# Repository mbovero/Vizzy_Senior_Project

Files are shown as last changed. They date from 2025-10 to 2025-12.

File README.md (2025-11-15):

<div align="center" style="margin-top:16px;margin-bottom:12px;">
  <h1 style="margin:0 0 6px 0;font-size:38px;line-height:1.15;letter-spacing:.3px;">
    Vizzy: Enhancing Robotic Manipulation with Vision-Enabled Large Language Models
  </h1>

  <div style="font-size:14px;color:#6a737d;margin-bottom:10px;">
    University of Utah — Electrical & Computer Engineering Capstone
  </div>

  <div style="font-size:15px;margin-bottom:14px;">
    Authors: Burke Dambly · Miles Bovero · Lawrence Ponce · Brian Stites · Jesse Jenkins
  </div>
  <br>
  <!-- tech badges -->
  <div style="margin-bottom:14px;">
    
    
    
    
    
  </div>

  <hr style="margin:0 auto;border:0;height:1px;width:90%;background:linear-gradient(90deg,rgba(0,0,0,0),rgba(140,140,140,.35),rgba(0,0,0,0));" />
</div>

## System Showcase
<!-- Two side-by-side GIFs -->
<div align="center" style="display:flex; justify-content:center; gap:20px; margin-top:20px; margin-bottom:16px;">
  Vizzy motion demo
  Vizzy vision detection demo
</div>

<p align="center" style="font-size:14px; color:#666;">
  <em>Figure 1 — Left: Arm motion demonstration · Right: Vision-based object detection in action.</em>
</p>

## Overview

<!-- Overview Section -->
<div style="margin-top:24px; margin-bottom:24px; padding:18px 22px; border-left:4px solid #2563eb; background:rgba(37,99,235,0.05); border-radius:8px;">
  <p style="margin:0 0 12px 0;">
    <strong>Vizzy</strong> is a modular 5-axis robotic arm designed to demonstrate the integration of 
    <strong>computer vision</strong>, <strong>inverse kinematics</strong>, and 
    <strong>large language model (LLM)</strong> reasoning for adaptive robotic control.  
    The project explores how artificial intelligence can make robotic systems more flexible and user-friendly 
    by combining visual perception and semantic reasoning into a single integrated robotic platform.
  </p>

  <p style="margin:0;">
    Unlike traditional robotic systems that require explicit programming and rigid motion paths, Vizzy enables 
    high-level natural language interaction. Through vision-based object detection and LLM-driven task scheduling, 
    the system can autonomously interpret and execute user requests.
  </p>
</div>

<p align="center">
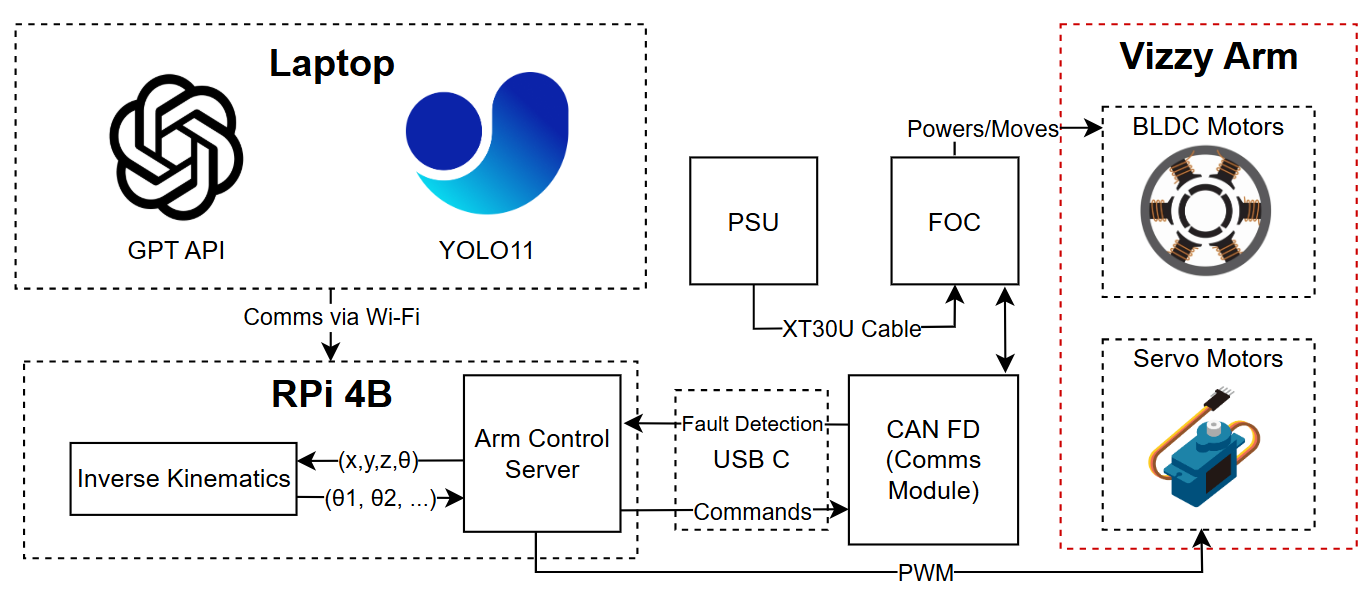
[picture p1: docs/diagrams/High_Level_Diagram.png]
Vizzy System Diagram
  
</p>

<p align="center"><em>Figure 2 — Conceptual overview of Vizzy’s modular arm system.</em></p>

<hr style="margin-top:28px; margin-bottom:0; border:0; height:1px; background:linear-gradient(90deg,rgba(0,0,0,0),rgba(140,140,140,.35),rgba(0,0,0,0));" />

## System Architecture

### Hardware

- **Motors:** MJBOTS mj5208 BLDC outrunner motors  
- **Motor Controllers:** Moteus r.11 (Field-Oriented Control)  
- **Microcontrollers:** Raspberry Pi 4B
- **Sensors:** 16MP USB camera and VL53L1X time-of-flight sensor  
- **Communication:** CAN-FD network using the Moteus protocol  
- **Structure:** CNC-milled T2-grade aluminum and PETG-CF 3D-printed components   
- **Power Supply:** Mean Well 24V .625A DC Power Supply 

<!-- 3x2 image grid for README -->
<table align="center">
  <tr>
    <td align="center">
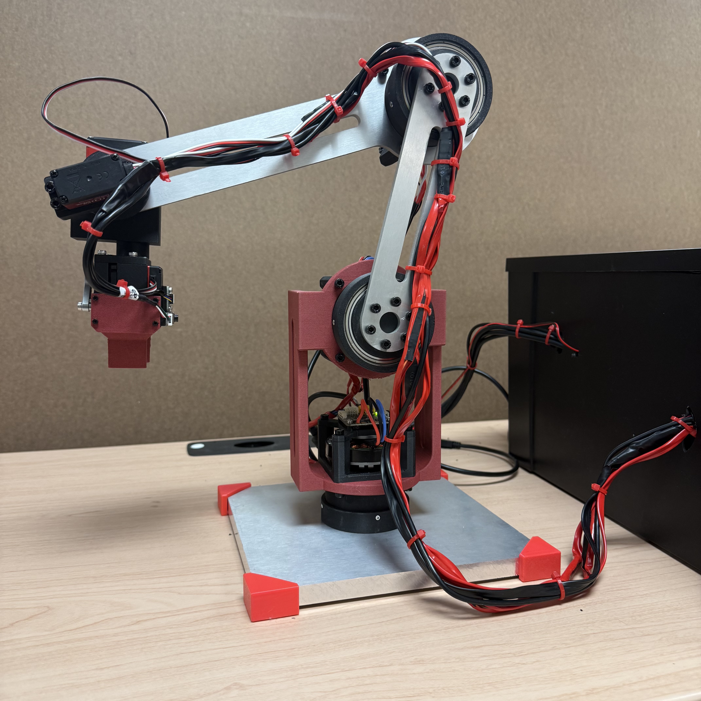
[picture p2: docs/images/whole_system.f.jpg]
Arm Assembly
      
      <div style="font-size:12px;color:#999;margin-top:6px;">Vizzy System</div>
    </td>
    <td align="center">
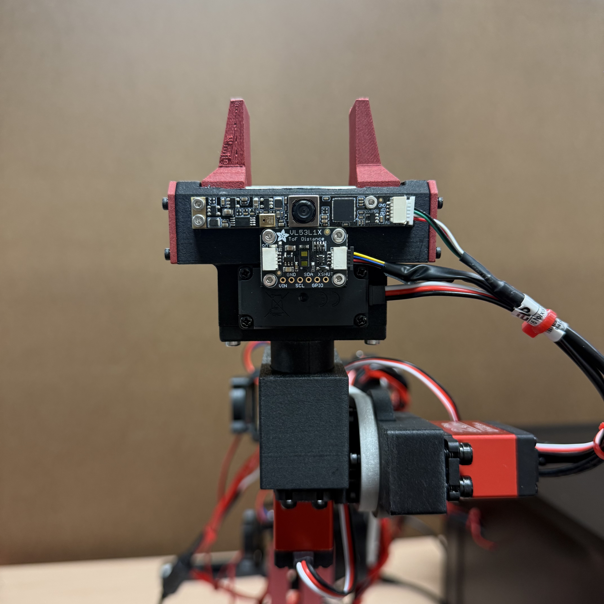
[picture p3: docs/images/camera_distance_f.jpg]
Joint Close-Up
      
      <div style="font-size:12px;color:#999;margin-top:6px;">Camera and ToF Sensor</div>
    </td>
    <td align="center">
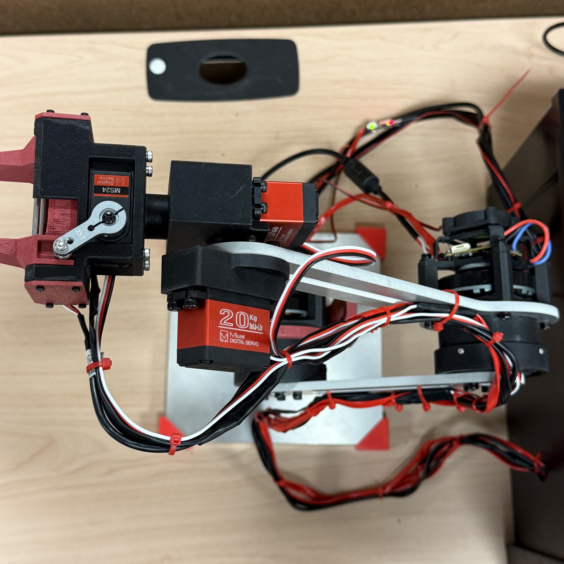
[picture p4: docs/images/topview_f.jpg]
Moteus Controllers
      
      <div style="font-size:12px;color:#999;margin-top:6px;">Upper Assembly</div>
    </td>
  </tr>
  <tr>
    <td align="center">
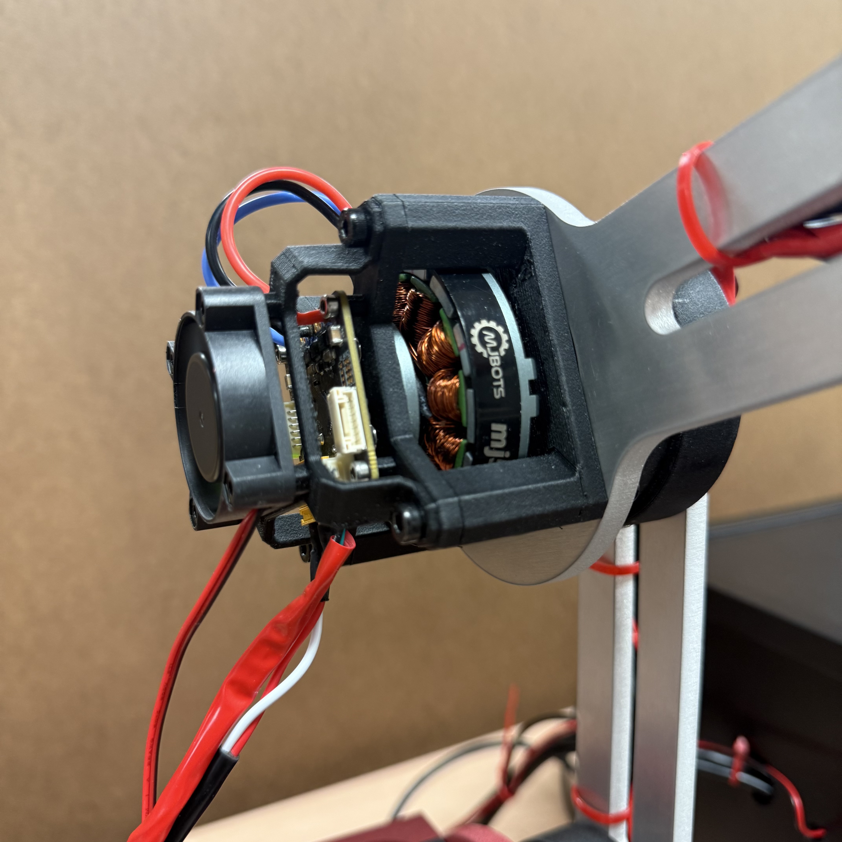
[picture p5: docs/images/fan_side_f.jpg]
Electronics Hub
      
      <div style="font-size:12px;color:#999;margin-top:6px;">Cooling System</div>
    </td>
    <td align="center">
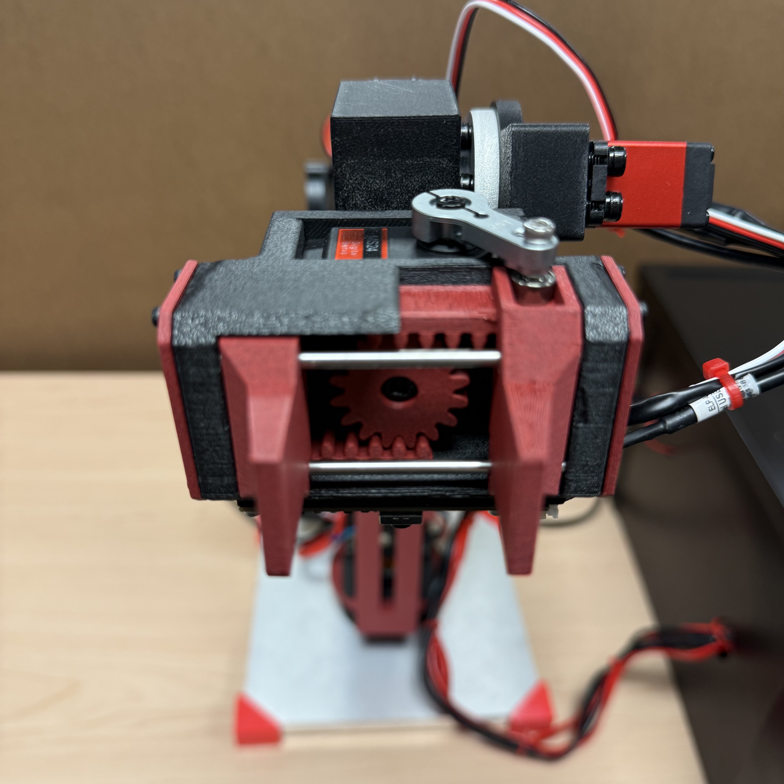
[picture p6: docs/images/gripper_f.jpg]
Camera Mount
      
      <div style="font-size:12px;color:#999;margin-top:6px;">End Effector</div>
    </td>
    <td align="center">
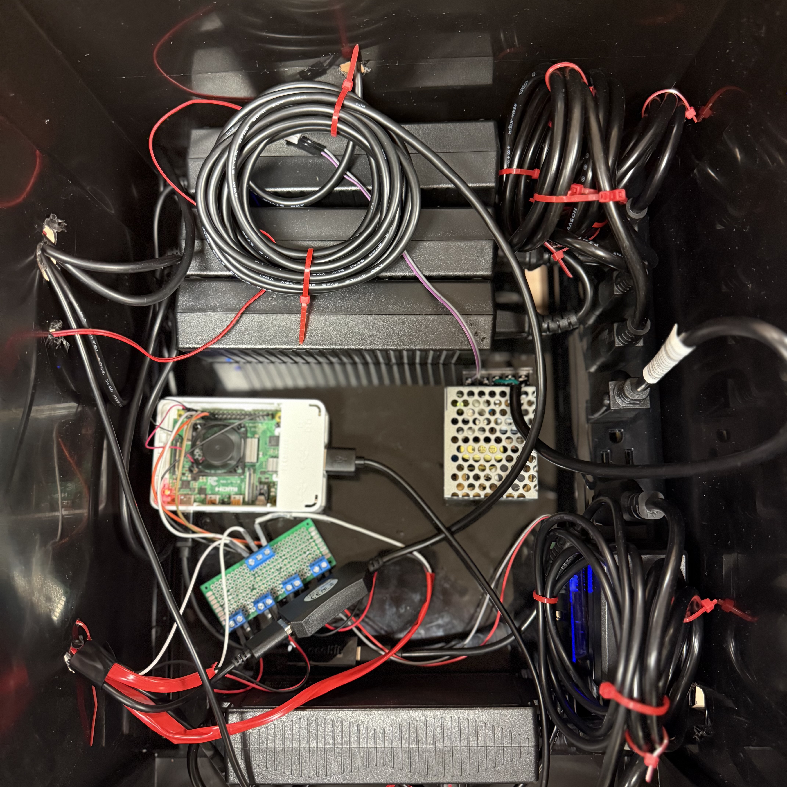
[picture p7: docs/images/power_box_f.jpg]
Power System
      
      <div style="font-size:12px;color:#999;margin-top:6px;">"Black Box" Power</div>
    </td>
  </tr>
</table>

<p align="center"><em>Figure 3 — Hardware overview showing mechanical components.</em></p>

<h3 id="software">Software</h3>

<ul style="margin-top:6px;margin-bottom:12px;">
  <li><strong>Vision Stack:</strong> YOLO11 model for object classification and mask segmentation</li>
  <li><strong>Semantic Layer:</strong> LLM-based contextual enrichment of detected objects</li>
  <li><strong>Task Scheduler:</strong> LLM-based task composition based on user request</li>
  <li><strong>Control Framework:</strong> Python API for inverse kinematics and task execution</li>
</ul>

<p align="center" style="margin-top:10px;">
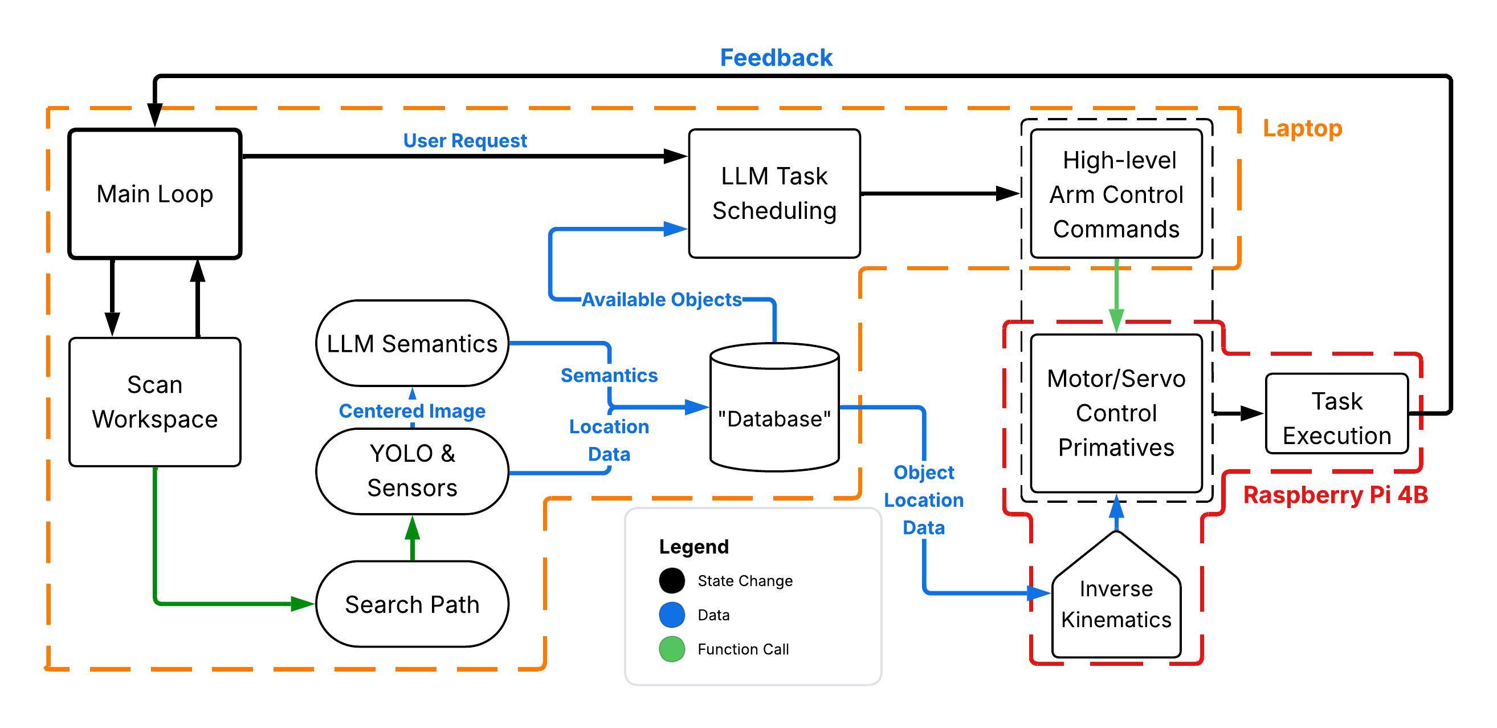
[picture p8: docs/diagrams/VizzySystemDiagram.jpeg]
Software Architecture Diagram
  
</p>
<p align="center" style="margin-top:4px;">
  <em>Figure 4 — Software architecture illustrating perception, reasoning, and control flow.</em>
</p>

---
<h2 id="about-the-authors" align="center">About the Authors</h2>

<table style="width:100%;border-collapse:separate;border-spacing:18px 14px;">
  <tr align="center" valign="top">
    <td style="width:33%;border:1px solid #d0d7de;border-radius:10px;padding:16px;background:#fafbfc;">
      <strong>Burke Dambly</strong><br>
      <em style="color:#57606a;">Computer Engineering</em><br>
      Focused on control systems, embedded firmware, and integration of Moteus-controlled BLDC actuators with high-level Python logic.
    </td>
    <td style="width:33%;border:1px solid #d0d7de;border-radius:10px;padding:16px;background:#fafbfc;">
      <strong>Miles Bovero</strong><br>
      <em style="color:#57606a;">Computer Engineering</em><br>
      Designed subsystem interfaces, YOLO-based vision pipeline, object centering / location / orientation estimation algorithms.
    </td>
    <td style="width:33%;border:1px solid #d0d7de;border-radius:10px;padding:16px;background:#fafbfc;">
      <strong>Lawrence Ponce</strong><br>
      <em style="color:#57606a;">Computer Engineering</em><br>
      Developed semantic enrichment and LLM-based task scheduling, enabling natural language driven task execution.
    </td>
    
  </tr>

  <tr align="center" valign="top">
    <td style="width:33%;border:1px solid #d0d7de;border-radius:10px;padding:16px;background:#fafbfc;">
      <strong>Brian Stites</strong><br>
      <em style="color:#57606a;">Computer Engineering</em><br>
      Designed and assembled the power distribution and safety systems for the robotic arm.
    </td>
    <td style="width:33%;border:1px solid #d0d7de;border-radius:10px;padding:16px;background:#fafbfc;">
      <strong>Jesse Jenkins</strong><br>
      <em style="color:#57606a;">Computer Science</em><br>
      Contributed to the inverse kinematics (IK) framework for precise arm positioning and control.
    </td>
    <td style="width:33%;border:1px dashed #d0d7de;border-radius:10px;padding:16px;background:#fafbfc;">
      <strong>Neal Patwari</strong><br>
      <em style="color:#57606a;">Faculty Advisor</em><br>
      Provided guidance on system integration and research methodology throughout the Vizzy capstone project.
    </td>
  </tr>
</table>

## Acknowledgements

This project was developed as part of the University of Utah Electrical and Computer Engineering Capstone Program.  
Special thanks to the faculty mentors and the Utah Machine Shop for technical support and machining resources.

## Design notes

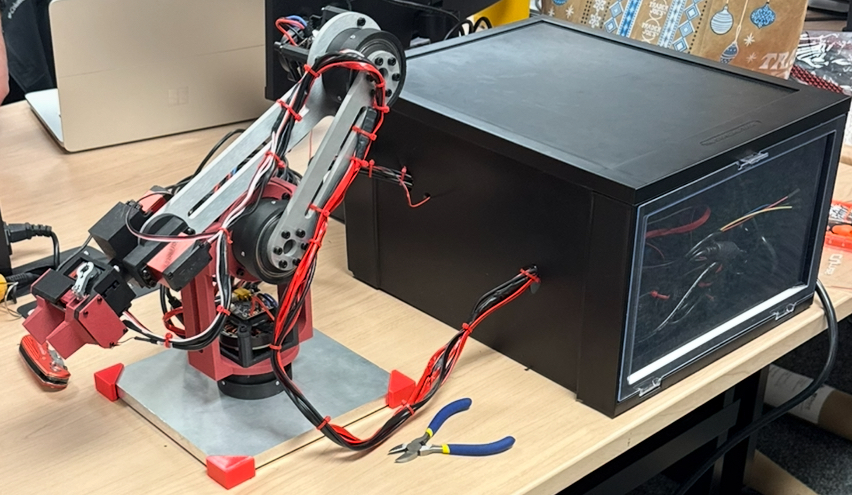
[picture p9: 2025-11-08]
docs/images/ArmOnDesk.jpg

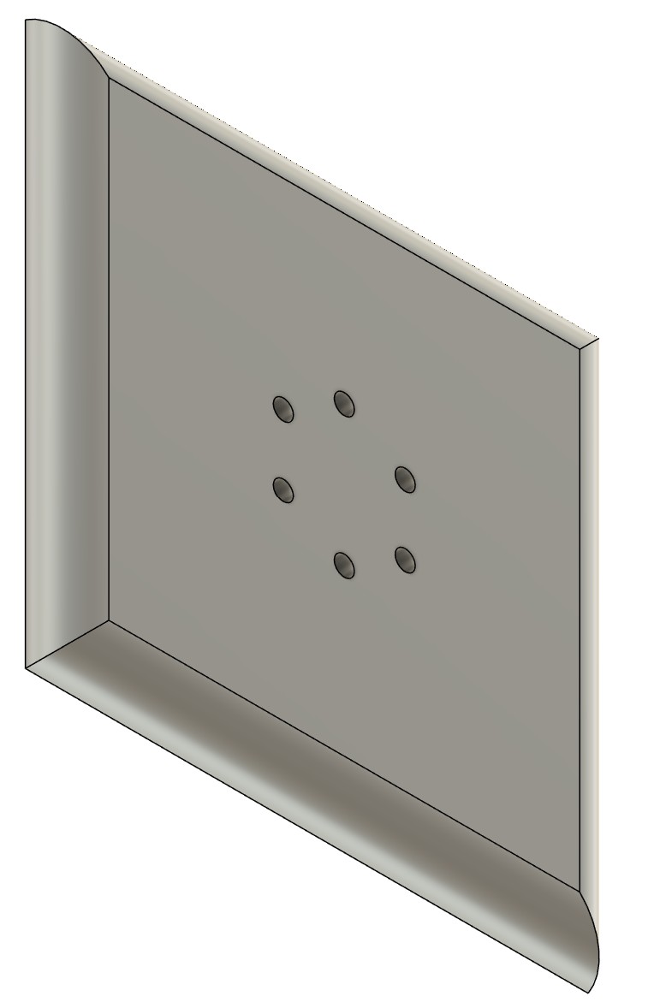
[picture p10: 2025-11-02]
docs/CAD/screenshots/Base v1.jpg

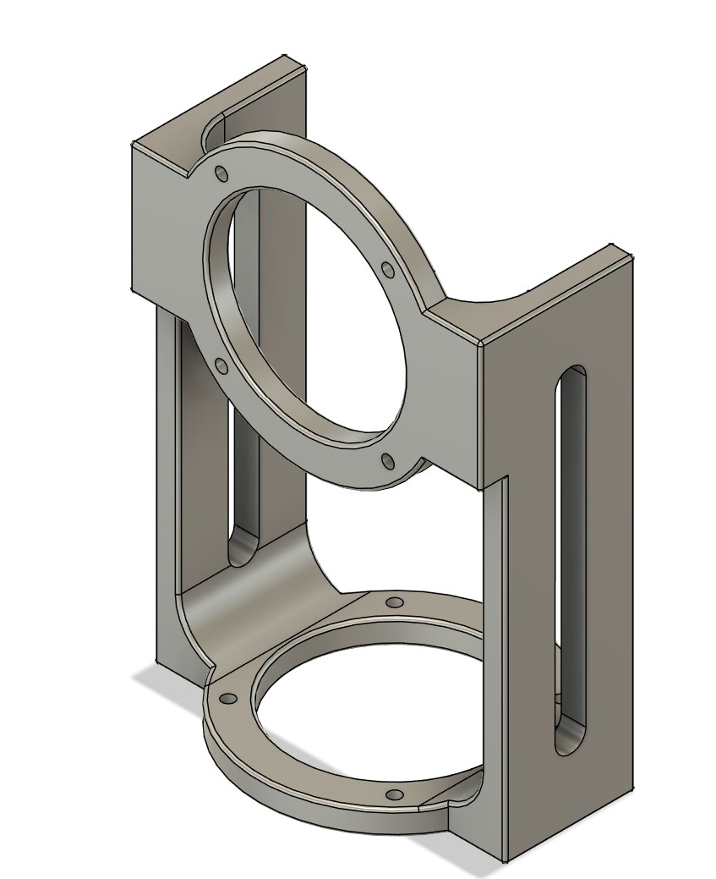
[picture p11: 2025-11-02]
docs/CAD/screenshots/Bottom Linkage v9.jpg

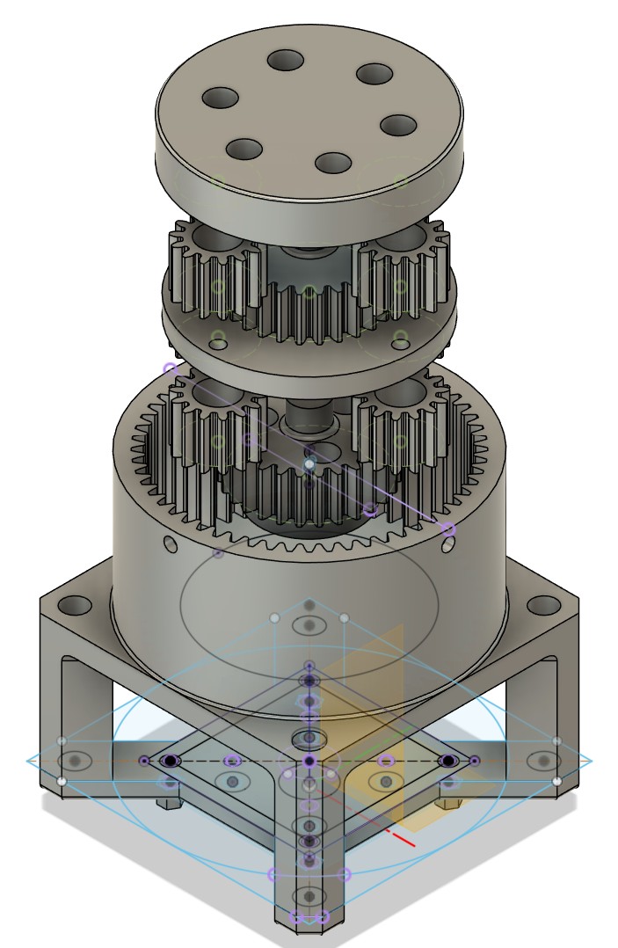
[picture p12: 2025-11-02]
docs/images/C1Gearbox.jpg

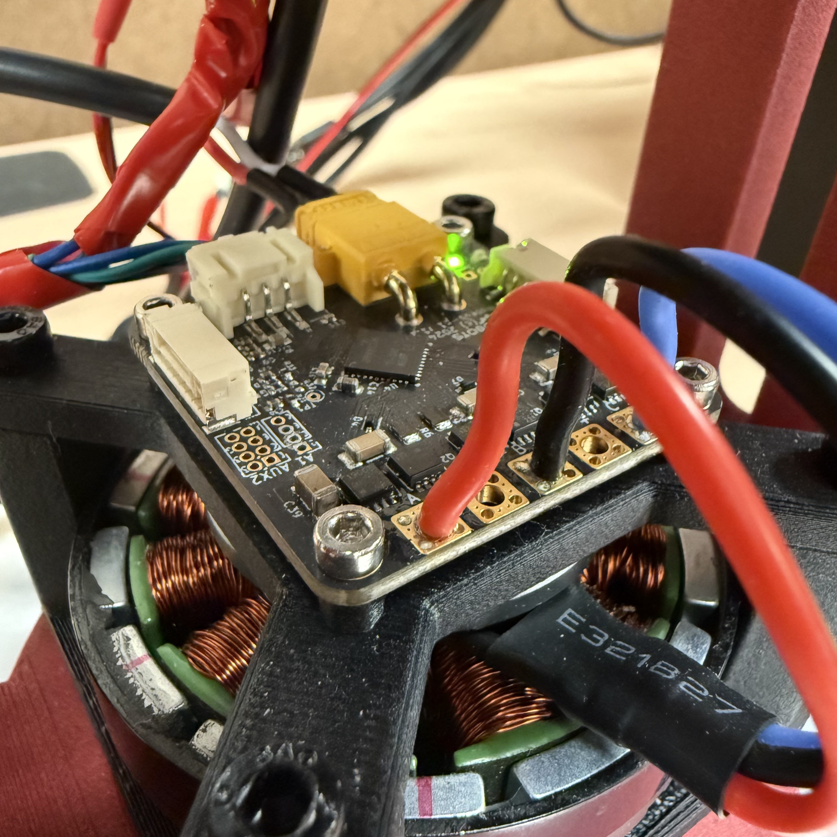
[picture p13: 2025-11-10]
docs/images/moteus_c_f.jpg

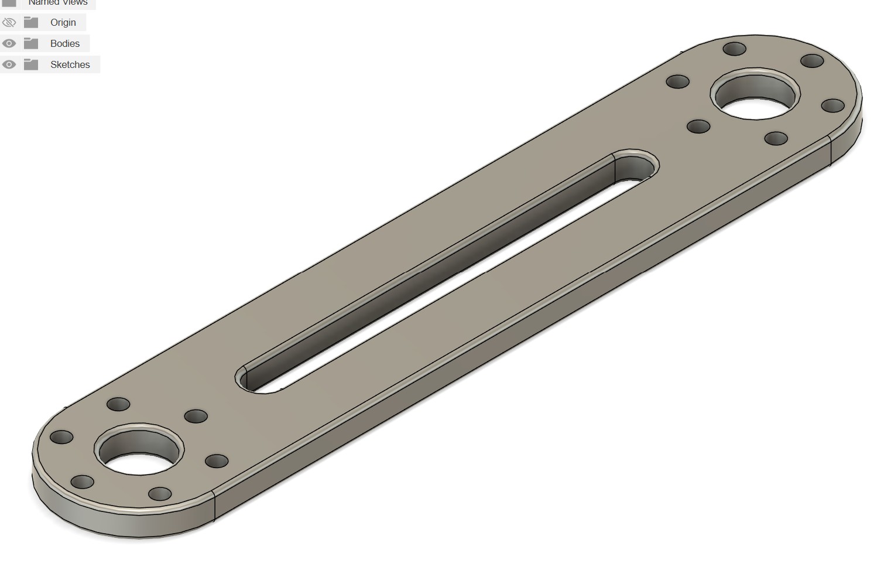
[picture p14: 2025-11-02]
docs/CAD/screenshots/Arm Link v5.jpg

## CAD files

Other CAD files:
docs/CAD/raw/20Kg Servo Bracket v6.f3d
docs/CAD/raw/Arm Link v5.f3d
docs/CAD/raw/Base Bracket v7.f3d
docs/CAD/raw/Base v1.f3d
docs/CAD/raw/Bottom Linkage v9.f3d
docs/CAD/raw/Custom C1 Bracket v3.f3d
docs/CAD/raw/Down Bracket v2.f3d
docs/CAD/raw/End Effector v16.f3d
docs/CAD/raw/Experimental Hold v13.f3d
docs/CAD/raw/Fan Bracket v2.f3d
docs/CAD/raw/Gripper v30.f3d
docs/CAD/raw/Upper Arm v4.f3d

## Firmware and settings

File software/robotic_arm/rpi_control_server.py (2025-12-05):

#!/usr/bin/env python3
# rpi_arm_server.py — Pi-side control of 3 moteus motors + 3 GPIO hobby servos (pitch, yaw, claw)
# Protocol (from client):  ik x y z pitch_rad yaw_rad O|C
#   - Pitch: radians go into IK; we use IK's q4 (PWM) directly (preserves original behavior)
#   - Yaw:   radians mapped to your specified PWM endpoints
#   - Claw:  O=1700 (open), C=1200 (closed) - snaps immediately (no interpolation)
# Pitch and yaw servos tween in sync with the motor group move duration. Claw snaps immediately.

from __future__ import annotations
import argparse, asyncio, math, time, sys, contextlib, pprint, re

# ---------- Servo Pins (BCM) ----------
SERVO_YAW   = 4
SERVO_CLAW  = 17
SERVO_PITCH = 27

# ---------- Global PWM bounds ----------
SERVO_MIN    = 500
SERVO_MAX    = 2500

# Pitch center (original server behavior: pitch straight up)
SERVO_PITCH_CENTER = 1770

# Yaw PWM mapping (your exact endpoints)
YAW_PWM_CENTER = 1700
YAW_PWM_MIN    = 1025   # clockwise (negative)
YAW_PWM_MAX    = 2375   # counter-clockwise (positive)
YAW_RAD_MIN    = -math.pi/2   # -90°
YAW_RAD_MAX    =  math.pi/2   # +90°

# Claw PWM mapping (your exact endpoints)
CLAW_PWM_OPEN   = 1650
CLAW_PWM_CLOSED = 1300

# Tween timing for servos
SERVO_TWEEN_MIN_DT = 0.01   # s
SERVO_TWEEN_MAX_DT = 0.025  # s
IDLE_SLEEP          = 0.02   # s
DURATION_FLOOR_S    = 0.1    # s (if motors barely move)

# ---------- Moteus / IK ----------
import moteus
from ik_callable import make_default_arm, ik_cmds_bounded

# ---- IK Tunables ----
IK_RADIUS_M = 0.15
IK_Z_MIN    = 0.0
IK_Z_MAX    = 0.4

# ---- q2 linear scaling (map ±2.25 -> ±2.10, 0 -> 0) ----
Q2_MAX_IN   = 2.25
Q2_MAX_OUT  = 2.15
Q2_SCALE    = (Q2_MAX_OUT / Q2_MAX_IN)  # ~0.955...

# ---- Comm/Heartbeat ----
COMM_FAIL_THRESHOLD = 3
RECOVER_SLEEP_S     = 0.5
HEARTBEAT_S         = 2.0

# pigpio
try:
    import pigpio
except Exception as e:
    print("ERROR: pigpio not available. Install via: sudo apt-get install pigpio", file=sys.stderr)
    raise

# Optional transports
def build_transport(kind: str):
    kind = (kind or "pi3hat").lower()
    if kind == "pi3hat":
        try:
            import moteus_pi3hat
            return moteus_pi3hat.Pi3HatRouter()
        except Exception:
            print("WARN: pi3hat not available, falling back to default moteus transport.", file=sys.stderr)
            return None
    if kind.startswith("socketcan"):
        parts = kind.split(":", 1)
        iface = parts[1] if len(parts) > 1 else "can0"
        try:
            return moteus.SocketcanRouter(channel=iface)
        except Exception:
            print(f"WARN: socketcan {iface} not available, using default.", file=sys.stderr)
            return None
    return None

# ---- Tunables (motors) ----
ID1, ID2, ID3      = 1, 2, 3

REST1               = 0.0
REST2               = 1.0
REST3               = 3.25

STEP_SIZE_RAD       = 0.08
STEP_DELAY_S        = 0.01

ACCEL_LIMIT         = 4
VEL_LIMIT           = 8.0
HOLD_ACCEL_LIMIT    = 4.0
HOLD_VEL_LIMIT      = 4.0
WATCHDOG            = 15.0

GROUP_SPEED_RAD_S   = 1.6
ACCEL_MULT          = 2.4
MIN_SPEED           = 0.02
POS_TOL             = 0.01
SYNC_POLL_S         = 0.05
SYNC_TIMEOUT_EXTRA  = 0.1

TEMP_LIMIT          = 50.0
COOL_RESUME_TEMP    = 40.0

WIGGLE_AMPLITUDE    = 0.5
WIGGLE_REPS         = 2
WIGGLE_DWELL_S      = 0.15

# ---------- Helpers ----------
def ang_err(a: float, b: float) -> float:
    return math.remainder(a - b, 2.0 * math.pi)

def clamp(v, lo, hi):
    return lo if v < lo else hi if v > hi else v

def lerp(a, b, t):
    return a + (b - a) * t

def map_yaw_rad_to_pwm(rad: float) -> int:
    """Piecewise map radians to PWM using the exact center/min/max."""
    r = max(YAW_RAD_MIN, min(YAW_RAD_MAX, rad))
    if abs(r) < 1e-12:
        return YAW_PWM_CENTER
    if r < 0.0:
        # [YAW_RAD_MIN .. 0] -> [YAW_PWM_MIN .. YAW_PWM_CENTER]
        t = (r - YAW_RAD_MIN) / (0.0 - YAW_RAD_MIN)  # 0 at min, 1 at 0
        pwm = YAW_PWM_MIN + t * (YAW_PWM_CENTER - YAW_PWM_MIN)
    else:
        # [0 .. YAW_RAD_MAX] -> [YAW_PWM_CENTER .. YAW_PWM_MAX]
        t = r / YAW_RAD_MAX  # 0 at 0, 1 at max
        pwm = YAW_PWM_CENTER + t * (YAW_PWM_MAX - YAW_PWM_CENTER)
    return int(round(clamp(pwm, SERVO_MIN, SERVO_MAX)))

async def hold(ctrl: moteus.Controller, pos: float):
    await ctrl.set_position(
        position=float(pos),
        velocity=float('nan'),
        accel_limit=HOLD_ACCEL_LIMIT,
        velocity_limit=HOLD_VEL_LIMIT,
        watchdog_timeout=WATCHDOG,
        query=False,
    )

async def move_ramped(ctrl: moteus.Controller, current: float, target: float) -> float:
    delta = ang_err(target, current)
    steps = max(1, int(abs(delta) / STEP_SIZE_RAD))
    step  = delta / steps
    pos   = current
    for _ in range(steps):
        pos += step
        await hold(ctrl, pos)
        await asyncio.sleep(STEP_DELAY_S)
    await hold(ctrl, target)
    return target

# on_duration callback receives the chosen group move duration (seconds)
async def move_group_sync_time(items, on_duration=None):
    if not items:
        return []
    deltas = [ang_err(t, c) for (_, c, t) in items]
    max_delta = max(abs(d) for d in deltas) if deltas else 0.0

    if max_delta < 1e-9:
        duration = DURATION_FLOOR_S
        if on_duration is not None:
            asyncio.create_task(on_duration(duration))
        await asyncio.gather(*(hold(ctrl, tgt) for (ctrl, _, tgt) in items))
        return [t for (_, _, t) in items]

    group_speed = max(GROUP_SPEED_RAD_S, MIN_SPEED)
    duration = max(max_delta / group_speed, DURATION_FLOOR_S)

    if on_duration is not None:
        asyncio.create_task(on_duration(duration))

    cmds = []
    for (ctrl, cur, tgt), d in zip(items, deltas):
        vel_lim = max(abs(d) / duration, MIN_SPEED)
        acc_lim = max(vel_lim * ACCEL_MULT, ACCEL_LIMIT)
        cmds.append(ctrl.set_position(
            position=float(tgt),
            velocity=float('nan'),
            accel_limit=acc_lim,
            velocity_limit=vel_lim,
            watchdog_timeout=WATCHDOG,
            query=False,
        ))
    await asyncio.gather(*cmds)

    t_end = time.monotonic() + duration + SYNC_TIMEOUT_EXTRA
    ctrls   = [ctrl for (ctrl, _, _) in items]
    targets = [t for (_, _, t) in items]

    while True:
        if time.monotonic() >= t_end:
            break
        try:
            states = await asyncio.gather(*(ctrl.query() for ctrl in ctrls))
            pos = [float(st.values.get('position', 0.0)) for st in states]
        except Exception:
            pos = [None] * len(ctrls)

        if all(p is not None and abs(ang_err(t, p)) <= POS_TOL
               for p, t in zip(pos, targets)):
            break
        await asyncio.sleep(SYNC_POLL_S)

    await asyncio.gather(*(hold(ctrl, tgt) for ctrl, tgt in zip(ctrls, targets)))
    return targets

def extract_temperature(vals: dict):
    try:
        temp = vals.get(moteus.Register.TEMPERATURE)
        if isinstance(temp, (int, float)):
            return float(temp)
    except Exception:
        pass
    temp = vals.get(0x00e)
    if not isinstance(temp, (int, float)):
        temp = vals.get(14)
    return float(temp) if isinstance(temp, (int, float)) else None

def extract_voltage(vals: dict):
    for k in ("voltage", "motor_voltage", "bus_voltage",
              getattr(moteus, "Register", object()).__dict__.get("VOLTAGE") if hasattr(moteus, "Register") else None,
              0x010, 16):
        if k in vals and isinstance(vals[k], (int, float)):
            return float(vals[k])
    return None

def has_fault(vals: dict) -> bool:
    f = vals.get("fault", 0)
    if isinstance(f, (int, float)) and f != 0:
        return True
    for k, v in vals.items():
        kn = str(k).lower()
        if kn.startswith("fault") or kn.startswith("error"):
            if isinstance(v, (int, float)) and v != 0:
                return True
            if isinstance(v, str) and v.strip():
                return True
    return False

def collect_fault_fields(vals: dict) -> dict:
    out = {}
    for key in ("fault", "fault_state", "fault_code", "fault_information", "error", "last_error"):
        if key in vals:
            out[key] = vals[key]
    for k, v in vals.items():
        kn = str(k).lower()
        if (kn.startswith("fault") or kn.startswith("error")) and (k not in out):
            out[k] = v
    return out

async def gentle_clear_fault(ctrl: moteus.Controller, name: str):
    try:
        await ctrl.set_stop()
        await asyncio.sleep(0.05)
        st = await ctrl.query()
        if not has_fault(st.values):
            print(f"[rpi] FAULT-CLEAR: {name} cleared by stop().")
        else:
            print(f"[rpi] FAULT-PERSIST: {name} still faulted after stop().", file=sys.stderr)
    except Exception as e:
        print(f"[rpi] FAULT-CLEAR-ERR: {name} stop/query raised: {e}", file=sys.stderr)

# ---------- Server ----------
class ArmServer:
    def __init__(self, host: str, port: int, _unused_servo_pin: int, transport_kind: str):
        self.host = host
        self.port = port

        # pigpio (single daemon controls all three servos)
        self.pi = pigpio.pi()
        if not self.pi.connected:
            raise RuntimeError("pigpio daemon not running. Start with: sudo systemctl start pigpiod")

        # Servo channels state (startup pose: pitch up, yaw centered, claw open)
        self.servos = {
            "pitch": {"pin": SERVO_PITCH, "current": SERVO_PITCH_CENTER, "target": SERVO_PITCH_CENTER},
            "yaw":   {"pin": SERVO_YAW,   "current": YAW_PWM_CENTER,     "target": YAW_PWM_CENTER},
            "claw":  {"pin": SERVO_CLAW,  "current": CLAW_PWM_OPEN,      "target": CLAW_PWM_OPEN},
        }
        for ch in self.servos.values():
            self.pi.set_servo_pulsewidth(ch["pin"], ch["current"])

        # moteus controllers
        self._transport_kind = transport_kind
        router = build_transport(transport_kind)
        self.m1 = moteus.Controller(id=ID1, transport=router)
        self.m2 = moteus.Controller(id=ID2, transport=router)
        self.m3 = moteus.Controller(id=ID3, transport=router)

        # IK arm instance
        self.ik_arm = make_default_arm()

        # Targets/state (motors)
        self.t1 = self.t2 = self.t3 = 0.0
        self.c1 = self.c2 = self.c3 = 0.0

        # Cooling / comm
        self.cooling2 = False
        self.cooling3 = False
        self.last_temp2 = None
        self.last_temp3 = None
        self._comm_failures = 0

        self._lock = asyncio.Lock()
        self._stop = asyncio.Event()
        self._servo_task: asyncio.Task | None = None
        self._pi_reconnect_backoff_s = 0.5

    # ===== pigpio resilience =====
    async def _ensure_pi(self):
        """Ensure pigpio connection is alive; (re)connect if needed."""
        if (self.pi is not None) and getattr(self.pi, "connected", False):
            return
        try:
            if self.pi is not None and getattr(self.pi, "connected", False):
                self.pi.stop()
        except Exception:
            pass

        start = time.monotonic()
        while True:
            self.pi = pigpio.pi()
            if getattr(self.pi, "connected", False):
                # Re-apply current PWM to channels so state is consistent
                for _, ch in self.servos.items():
                    try:
                        self.pi.set_servo_pulsewidth(ch["pin"], int(ch["current"]))
                    except Exception:
                        try: self.pi.stop()
                        except Exception: pass
                        self.pi = None
                        await asyncio.sleep(self._pi_reconnect_backoff_s)
                        continue
                if self._pi_reconnect_backoff_s < 2.0:
                    self._pi_reconnect_backoff_s *= 1.25
                print("[rpi] pigpio reconnected.")
                return
            self.pi = None
            await asyncio.sleep(self._pi_reconnect_backoff_s)
            if (time.monotonic() - start) > 5.0:
                print("[rpi] WARN: pigpio reconnect still pending...")
                start = time.monotonic()

    async def _safe_servo_write(self, name: str, pwm_us: int):
        """Write with auto-reconnect protection."""
        try:
            await self._ensure_pi()
            await self._servo_write_pwm(name, pwm_us)
        except (AttributeError, pigpio.error, OSError) as e:
            print(f"[rpi] pigpio write error ({name}): {e} → reconnecting...", file=sys.stderr)
            try:
                if self.pi is not None:
                    self.pi.stop()
            except Exception:
                pass
            self.pi = None
            await self._ensure_pi()
            await self._servo_write_pwm(name, pwm_us)

    async def _cancel_servo_task(self):
        """Cancel any in-flight tween task cleanly."""
        if self._servo_task and not self._servo_task.done():
            self._servo_task.cancel()
            with contextlib.suppress(asyncio.CancelledError):
                await self._servo_task
        self._servo_task = None

    async def _start_servo_tween(self, duration: float):
        """Ensure only one tween task runs; start a new one for 'duration'."""
        await self._cancel_servo_task()
        self._servo_task = asyncio.create_task(self.servos_tween_multi(duration))

    # ===== SERVO I/O =====
    async def _servo_write_pwm(self, name: str, pwm_us: int):
        ch = self.servos[name]
        pwm = int(clamp(pwm_us, SERVO_MIN, SERVO_MAX))
        self.pi.set_servo_pulsewidth(ch["pin"], pwm)
        ch["current"] = pwm

    def set_servo_targets(self, *, pitch_pwm: int | None = None, yaw_pwm: int | None = None, claw_pwm: int | None = None):
        if pitch_pwm is not None:
            self.servos["pitch"]["target"] = int(clamp(pitch_pwm, SERVO_MIN, SERVO_MAX))
        if yaw_pwm is not None:
            self.servos["yaw"]["target"]   = int(clamp(yaw_pwm,   SERVO_MIN, SERVO_MAX))
        if claw_pwm is not None:
            # Claw target set (will be continuously sent)
            self.servos["claw"]["target"]  = int(clamp(claw_pwm,  SERVO_MIN, SERVO_MAX))

    async def servos_tween_multi(self, duration: float):
        """Tween pitch and yaw linearly from their current to target PWM over 'duration' seconds.
        Claw PWM is continuously sent at target value (no interpolation)."""
        await self._ensure_pi()

        t_claw = self.servos["claw"]["target"]

        if duration <= 0.0:
            await asyncio.gather(
                self._safe_servo_write("pitch", self.servos["pitch"]["target"]),
                self._safe_servo_write("yaw",   self.servos["yaw"]["target"]),
                self._safe_servo_write("claw",  t_claw),
            )
            return

        s_pitch, t_pitch = self.servos["pitch"]["current"], self.servos["pitch"]["target"]
        s_yaw,   t_yaw   = self.servos["yaw"]["current"],   self.servos["yaw"]["target"]

        t0 = time.monotonic()
        dt = max(SERVO_TWEEN_MIN_DT, min(SERVO_TWEEN_MAX_DT, duration / 50.0))
        while True:
            el = time.monotonic() - t0
            if el >= duration:
                break
            a = el / duration
            # Continuously send claw PWM along with pitch/yaw updates
            await asyncio.gather(
                self._safe_servo_write("pitch", int(round(lerp(s_pitch, t_pitch, a)))),
                self._safe_servo_write("yaw",   int(round(lerp(s_yaw,   t_yaw,   a)))),
                self._safe_servo_write("claw",  t_claw),
            )
            await asyncio.sleep(dt)

        await asyncio.gather(
            self._safe_servo_write("pitch", t_pitch),
            self._safe_servo_write("yaw",   t_yaw),
            self._safe_servo_write("claw",  t_claw),
        )

    async def servos_snap(self, *, pitch_pwm: int, yaw_pwm: int, claw_pwm: int):
        """Set servos *once* without tweening. Best-effort; won't block the motor park."""
        self.set_servo_targets(pitch_pwm=pitch_pwm, yaw_pwm=yaw_pwm, claw_pwm=claw_pwm)
        with contextlib.suppress(Exception):
            await self._cancel_servo_task()
        try:
            await self._ensure_pi()
            await asyncio.gather(
                self._safe_servo_write("pitch", self.servos["pitch"]["target"]),
                self._safe_servo_write("yaw",   self.servos["yaw"]["target"]),
                self._safe_servo_write("claw",  self.servos["claw"]["target"]),
            )
        except Exception as e:
            print(f"[rpi] EMERG: servo snap failed (continuing cooldown): {e}", file=sys.stderr)

    async def park_to_rest_emergency(self):
        """Emergency cooldown: snap servos, then motor-only blocking park to REST."""
        await self.servos_snap(
            pitch_pwm=SERVO_PITCH_CENTER,
            yaw_pwm=YAW_PWM_CENTER,
            claw_pwm=CLAW_PWM_OPEN
        )
        finals = await move_group_sync_time([
            (self.m1, self.c1, REST1),
            (self.m2, self.c2, REST2),
            (self.m3, self.c3, REST3),
        ], on_duration=None)
        self.c1, self.c2, self.c3 = finals
        self.t1, self.t2, self.t3 = REST1, REST2, REST3
        await asyncio.gather(
            hold(self.m1, REST1),
            hold(self.m2, REST2),
            hold(self.m3, REST3),
        )

    # ===== MOTEUS & SYSTEM =====
    async def init_positions(self):
        await asyncio.gather(self.m1.set_stop(), self.m2.set_stop(), self.m3.set_stop())
        try:
            s1, s2, s3 = await asyncio.gather(self.m1.query(), self.m2.query(), self.m3.query())
            self.t1 = self.c1 = float(s1.values.get('position', 0.0))
            self.t2 = self.c2 = float(s2.values.get('position', 0.0))
            self.t3 = self.c3 = float(s3.values.get('position', 0.0))
            await self._report_fault_if_any("m1", s1.values); await self._report_fault_if_any("m2", s2.values); await self._report_fault_if_any("m3", s3.values)
        except Exception as e:
            print(f"[rpi] init: query error: {e}", file=sys.stderr)
            self.t1 = self.t2 = self.t3 = 0.0
            self.c1 = self.c2 = self.c3 = 0.0
        print(f"[rpi] init: ID1={self.c1:.3f}, ID2={self.c2:.3f}, ID3={self.c3:.3f}")

    async def _recover_bus(self):
        print("[rpi] COMM: attempting bus recovery...", file=sys.stderr)
        with contextlib.suppress(Exception):
            await asyncio.gather(self.m1.set_stop(), self.m2.set_stop(), self.m3.set_stop())

        router = build_transport(self._transport_kind)
        self.m1 = moteus.Controller(id=ID1, transport=router)
        self.m2 = moteus.Controller(id=ID2, transport=router)
        self.m3 = moteus.Controller(id=ID3, transport=router)

        # Park servos to your safe defaults (best-effort)
        await self.servos_snap(
            pitch_pwm=SERVO_PITCH_CENTER,
            yaw_pwm=YAW_PWM_CENTER,
            claw_pwm=CLAW_PWM_OPEN
        )
        await asyncio.sleep(RECOVER_SLEEP_S)
        self._comm_failures = 0
        print("[rpi] COMM: recovery complete.")

    async def _report_fault_if_any(self, name: str, vals: dict):
        if has_fault(vals):
            ff = collect_fault_fields(vals)
            print(f"[rpi] FAULT: {name}: {ff}", file=sys.stderr)
            await gentle_clear_fault(getattr(self, name), name)

    async def control_loop(self):
        next_temp = time.monotonic()
        try:
            while not self._stop.is_set():
                async with self._lock:
                    group = [
                        (self.m1, self.c1, self.t1),
                        (self.m2, self.c2, self.t2),
                        (self.m3, self.c3, self.t3),
                    ]

                    try:
                        finals = await move_group_sync_time(group, on_duration=self._start_servo_tween)
                        self.c1, self.c2, self.c3 = finals
                        self._comm_failures = 0
                    except Exception as e:
                        self._comm_failures += 1
                        print(f"[rpi] COMM: move_group exception ({self._comm_failures}/{COMM_FAIL_THRESHOLD}): {e}", file=sys.stderr)
                        if self._comm_failures >= COMM_FAIL_THRESHOLD:
                            await self._recover_bus()

                now = time.monotonic()
                if now >= next_temp:
                    try:
                        s2, s3 = await asyncio.gather(self.m2.query(), self.m3.query())
                        self.last_temp2 = extract_temperature(s2.values)
                        self.last_temp3 = extract_temperature(s3.values)
                        await self._report_fault_if_any("m2", s2.values)
                        await self._report_fault_if_any("m3", s3.values)
                    except Exception as e:
                        self._comm_failures += 1
                        print(f"[rpi] COMM: temp query exception ({self._comm_failures}/{COMM_FAIL_THRESHOLD}): {e}", file=sys.stderr)
                        if self._comm_failures >= COMM_FAIL_THRESHOLD:
                            await self._recover_bus()
                    next_temp = now + 1.0

                # Over-temp handling → EMERGENCY PARK (motor-only, servos snapped best-effort)
                if (self.last_temp2 is not None) and (not self.cooling2) and (self.last_temp2 > TEMP_LIMIT):
                    print(f"[rpi] WARN: m2 > {TEMP_LIMIT:.1f} °C → EMERGENCY PARK (motor-only).")
                    await self.park_to_rest_emergency()
                    self.cooling2 = True

                if (self.last_temp3 is not None) and (not self.cooling3) and (self.last_temp3 > TEMP_LIMIT):
                    print(f"[rpi] WARN: m3 > {TEMP_LIMIT:.1f} °C → EMERGENCY PARK (motor-only).")
                    await self.park_to_rest_emergency()
                    self.cooling3 = True
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

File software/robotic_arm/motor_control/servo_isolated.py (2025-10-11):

import pigpio


pi = pigpio.pi()
init_servos(pi)



def init_servos(pi) -> None:
    """
    Initialize servo outputs at SERVO_CENTER so they are powered and not limp.
    Safe to call multiple times.
    """
    pi.set_servo_pulsewidth(C.SERVO_BTM, C.SERVO_CENTER)
    pi.set_servo_pulsewidth(C.SERVO_MID, C.SERVO_CENTER)
    pi.set_servo_pulsewidth(C.SERVO_TOP, C.SERVO_CENTER)
    state.current_horizontal = C.SERVO_CENTER
    state.current_vertical = C.SERVO_CENTER



# -----------------------------
# Servos & Sweep (RPi)
# -----------------------------
# Servo GPIO pins (BCM numbering for pigpio)
# Adjust to match your wiring.
SERVO_BTM = 0
SERVO_MID = 5
SERVO_TOP = 6

# Pulse width bounds (µs)
SERVO_MIN    = 1000
SERVO_MAX    = 2000
SERVO_CENTER = 1500

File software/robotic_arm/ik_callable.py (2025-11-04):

from __future__ import annotations
from dataclasses import dataclass, field
from math import atan2, cos, sin, sqrt, hypot, pi
from typing import Optional, Tuple, Dict

# ========================= USER SETUP CHECKLIST =========================
# 1) Set ArmParams geometry L1..L4 in meters (center-to-center distances).
# 2) Set JointCalib per joint: theta0 [rad], sign (+1/-1), limits [rad].
#    - If pwm_m/pwm_b are set, rad <-> PWM µs is used.
#    - Else, rad <-> motor turns is used via gear_ratio.
# 3) prefer_elbow_up: True/False branch.
# 4) In example_usage(): set your target_xyz (m) and target_pitch_rad (rad).
# =======================================================================

RAD2DEG = 180.0 / pi
DEG2RAD = pi / 180.0

# --- q4 servo mapping (270°, 500–2500 µs, center 1750 µs) ---
Q4_PWM_CENTER_US   = 1755
Q4_PWM_MIN_US      = 800.0
Q4_PWM_MAX_US      = 2500.0
Q4_PWM_HALFSPAN_US = 1000.0
Q4_MAX_DEG         = 135.0
Q4_US_PER_RAD      = Q4_PWM_HALFSPAN_US / (Q4_MAX_DEG * DEG2RAD)  # µs per rad


@dataclass
class JointCalib:
    """
    Calibration for a single joint.

    theta0: geometric angle (rad) corresponding to hardware logical zero.
            angle_math = sign * (angle_hw) + theta0
    sign: +1 if increasing hardware command increases positive geometric angle; else -1.

    Option A (PWM mapping):
      angle(rad) = pwm_m * PWM(µs) + pwm_b
      rad_to_cmd returns PWM µs; cmd_to_rad expects PWM µs.

    Option B (gear mapping; default):
      Commands are in motor turns (1.0 = one motor revolution), using gear_ratio.
    """
    theta0: float = 0.0
    sign: int = 1
    min_rad: float = -pi
    max_rad: float = pi

    pwm_m: Optional[float] = None
    pwm_b: Optional[float] = None

    gear_ratio: float = 1.0  # motor_turns / joint_turn

    def rad_to_cmd(self, q: float) -> float:
        """Geometric angle (rad) -> hardware command (PWM µs or motor turns)."""
        hw_angle_joint = self.sign * (q - self.theta0)
        if self.pwm_m is not None and self.pwm_b is not None:
            return (hw_angle_joint - self.pwm_b) / self.pwm_m
        return (self.gear_ratio * hw_angle_joint) / (2.0 * pi)

    def cmd_to_rad(self, cmd: float) -> float:
        """Hardware command -> geometric angle (rad)."""
        if self.pwm_m is not None and self.pwm_b is not None:
            hw_angle_joint = self.pwm_m * cmd + self.pwm_b
        else:
            hw_angle_joint = (cmd * 2.0 * pi) / self.gear_ratio
        return self.theta0 + self.sign * hw_angle_joint


@dataclass
class ArmParams:
    """
    Yaw–Pitch–Pitch–Pitch arm geometry and calibration.
    """
    L1: float
    L2: float
    L3: float
    L4: float = 0.0

    prefer_elbow_up: bool = False
    base_offset_x: float = 0.0
    base_offset_y: float = 0.0

    # Joint calibrations q1..q4 (yaw, shoulder, elbow, wrist)
    q1: JointCalib = field(default_factory=JointCalib)
    q2: JointCalib = field(default_factory=JointCalib)
    q3: JointCalib = field(default_factory=JointCalib)
    q4: JointCalib = field(default_factory=JointCalib)


class IKError(Exception):
    pass


def ik_yppp(
    arm: ArmParams,
    target_xyz: Tuple[float, float, float],
    target_pitch_rad: float,
) -> Dict[str, Dict[str, float]]:
    """
    Analytic IK for a yaw–pitch–pitch–pitch arm controlling (x, y, z, pitch).
    No joint-limit clamping; q1 is NOT wrapped.

    IMPORTANT: Use a signed planar wrist radius so small x motions near r=L4·cos(pitch)
    don't reverse due to |r - L4 cos(pitch)|.
    """
    x, y, z = target_xyz
    bx, by = arm.base_offset_x, arm.base_offset_y

    # 1) Base yaw from base (bx,by) toward (x,y)
    q1 = atan2(y - by, x - bx)  # [-pi, pi], y changes base rotation

    # TCP planar radius from base and vertical offset relative to shoulder
    r_tcp = hypot(x - bx, y - by)         # >= 0
    z_tcp = z

    # 2) Signed planar reduction directly in the yawed plane:
    px = (r_tcp - arm.L4 * cos(target_pitch_rad))
    pz = (z_tcp - arm.L4 * sin(target_pitch_rad)) - arm.L1

    # Reconstruct wrist coordinates (for debugging/telemetry)
    wx = bx + px * cos(q1)
    wy = by + px * sin(q1)
    wz = arm.L1 + pz

    # 3) Elbow via law of cosines (numeric clamp on D only)
    D = (px*px + pz*pz - arm.L2*arm.L2 - arm.L3*arm.L3) / (2.0 * arm.L2 * arm.L3)
    D = max(-1.0, min(1.0, D))

    s = sqrt(max(0.0, 1.0 - D*D))
    q3 = atan2(+s, D) if arm.prefer_elbow_up else atan2(-s, D)

    # 4) Shoulder (two-atan form)
    k1 = arm.L2 + arm.L3 * cos(q3)
    k2 = arm.L3 * sin(q3)
    q2 = atan2(pz, px) - atan2(k2, k1)

    # 5) Wrist pitch to achieve desired tool pitch
    q4 = target_pitch_rad - (q2 + q3)

    # Outputs
    angles_rad = {'q1': q1, 'q2': q2, 'q3': q3, 'q4': q4}
    angles_deg = {k: v * RAD2DEG for k, v in angles_rad.items()}

    # q4: radians -> PWM µs (saturate to electrical bounds only)
    q4_pwm = Q4_PWM_CENTER_US + q4 * Q4_US_PER_RAD
    q4_pwm = max(Q4_PWM_MIN_US, min(Q4_PWM_MAX_US, q4_pwm))

    cmds = {
        'q1': arm.q1.rad_to_cmd(q1),  # motor turns
        'q2': arm.q2.rad_to_cmd(q2),  # motor turns
        'q3': arm.q3.rad_to_cmd(q3),  # motor turns
        'q4': int(round(q4_pwm)),     # PWM µs
    }

    return {
        'angles_rad': angles_rad,
        'angles_deg': angles_deg,
        'cmds': cmds,
        'intermediate': {
            'wrist_xyz': (wx, wy, wz),
            'planar_px': px,
            'planar_pz': pz,
            'D': D,
            'k1': k1,
            'k2': k2,
            'r_tcp': r_tcp,
        }
    }


def max_height(arm: ArmParams) -> float:
    """Maximum vertical TCP height when the pitch stack is straight up (pitch = +pi/2)."""
    return arm.L1 + arm.L2 + arm.L3 + arm.L4


# -------------------- IMPORT-FRIENDLY WRAPPERS (NO IK LOGIC CHANGED) --------------------

def ik_solve(arm: ArmParams, target_xyz: Tuple[float, float, float], target_pitch_rad: float) -> Dict[str, Dict[str, float]]:
    """Return full IK solution dict."""
    return ik_yppp(arm, target_xyz, target_pitch_rad)


def ik_cmds(arm: ArmParams, target_xyz: Tuple[float, float, float], target_pitch_rad: float) -> Dict[str, float]:
    """Return only the 'cmds' dictionary."""
    return ik_yppp(arm, target_xyz, target_pitch_rad)['cmds']


def make_default_arm() -> ArmParams:
    """Build the same ArmParams used in example_usage()."""
    GR = 9.0
    return ArmParams(
        L1=0.176932,   # m
        L2=0.162737,   # m
        L3=0.226991,   # m
        L4=0.12047,    # m
        prefer_elbow_up=False,
        base_offset_x=0.0,
        base_offset_y=0.0,
        q1=JointCalib(theta0=0.0,    sign=+1, gear_ratio=GR),
        q2=JointCalib(theta0=pi/2.0, sign=+1, gear_ratio=GR),
        q3=JointCalib(theta0=0.0,    sign=-1, gear_ratio=GR),
        q4=JointCalib(theta0=0.0,    sign=+1, gear_ratio=GR),
    )


# -------------------- BOUNDING CYLINDER GUARD (IK LOGIC UNCHANGED) --------------------
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

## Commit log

2025-03-03 Add .gitkeep files to track empty directories
2025-03-04 Uploaded .ino and .py programs for interfacing with ArduCam Mega via ESP32
2025-03-04 Create README.md for ArduCam + ESP32 python scripts
2025-03-04 Add ArduCam Mega + ESP32 python scripts requirements.txt
2025-03-05 Created servo reset script for Proto Vizzy V2
    [reset_servos.py]
2025-06-28 Uploaded code from first operational arm centering code
2025-08-05 First proto vizzy v2 with togglable search mode. Only servo movement works while searching.
2025-08-05 Improved servo movement during search mode
2025-09-10 Sped up object centering for new camera
2025-09-10 Reconfigured camera settings for improved imaging (MJPG format) at higher FPS
2025-09-11 Added manual motor control script
2025-10-06 Added servo initialization
2025-10-06 Updated servo GPIO pins
2025-10-06 Updated servo movement config
2025-10-06 Fixed servo movement and centering
2025-10-07 Working query and task execution prototype
2025-10-07 copied rpi files for debugging; added mid servo pin
2025-10-07 Mid servo now configured upon servo init
2025-10-08 Added countdown to search timer to idle GUI
2025-10-09 Debug prints and solving display issues
2025-10-09 Additionaly debug prints for search state
2025-10-09 LLM debug prints
2025-10-09 switched to gpt-5-mini
2025-10-09 Debugging prints for user text
2025-10-11 Upload servo and motor code
2025-10-11 Updated servo test client/server
2025-10-11 disabled servos
2025-10-11 changes servo center
2025-10-11 reset servo centers
2025-10-11 Fixed servo ranges
2025-10-11 Reduced servo range
2025-10-11 Implement command dispatcher architecture with PCA-based orientation calculation
    Add primitive command system (PICK, PLACE, GRAB, RELEASE, MOVE_TO, ROT_YAW, ROT_PITCH) with one-at-a-time dispatcher execution and RPi stub handlers, plus PCA-based grasp orientation averaged over mu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
2025-10-13 Removed pwms if statement encapsulating functions in scan_worker.py
2025-10-13 Hopefully integration of dual terminal is working at this stage... lol
2025-10-15 Updated servo center
2025-10-16 Reverted servo changes
2025-10-17 Updated motor control config
2025-10-17 fixed inverse kinematics
2025-10-18 Added script for resetting servos
2025-10-18 Modified servo reset script to simply center all servos
    [reset_servos.py]
2025-10-18 Added manual servo control
2025-10-18 Changed servo GPIO pins
2025-10-18 Added sweep functionality to servo script
2025-10-18 Upload distance sensor data read script
2025-10-18 Updated servo centers
2025-10-19 Changed servo min range
2025-10-19 Added overheating handler for third motor
    [rpi_servo_server.py]
2025-10-19 added dev script for viewing camera feed
2025-10-19 Fixed gripper offset for IK
    [inverse_kinematics.py]
2025-11-01 Updated servo assignments and PWM ranges
2025-11-01 Lengthened watchdog timer to prevent faults
    [rpi_servo_server.py]
2025-11-01 Updated servo pin
2025-11-01 Fixed servo pin assignment
    [reset_servos.py, rpi_servo_server.py]
2025-11-01 Wrist servo position now reset when resting
    [rpi_servo_server.py]
2025-11-01 Applied offset to motor rotation
2025-11-01 Wrist servo resets first when resting
    [rpi_servo_server.py]
2025-11-01 Power cycling for faults
2025-11-01 Implemented arm controller heartbeat
2025-11-01 Tuned motor offset
2025-11-02 Refactored vizzy protocols and search pipeline to begin integrating with new arm
2025-11-02 added gui for manual arm control
2025-11-02 Added raw fusion files
    [20Kg Servo Bracket v6.f3d, Arm Link v5.f3d, Base Bracket v7.f3d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]
2025-11-03 Smoothed servo movement
2025-11-03 Added control to yaw and claw motors
2025-11-03 Created updated client for full arm control testing
2025-11-03 Tuned servo control and client-server interface
2025-11-04 Changed servo ranges
2025-11-04 Patched overheating and servo interpolation faults
    [rpi_control_server.py]
2025-11-08 Rename C1 Gearbox.jpg to C1Gearbox.jpg
2025-11-08 Rename Upper Arm.jpg to UpperArm.jpg
2025-11-08 Created prototype script for new object centering
2025-11-09 Fixed yaw servo center
    [rpi_control_server.py]
2025-11-10 fixed gui by removing destroying frames
2025-11-10 Fixed centering stalling
2025-11-10 Implemented camera offset awareness to improve object grasping
2025-11-11 Changed claw servo range for new claw grippers
2025-11-11 Reduce claw pinch delay
2025-11-15 Changed claw servo PWM for closed position
2025-11-15 Informed LLM of arm orientation with respect to xyz coordinates
2025-11-15 Claw now receives continuous PWM signals
2025-11-15 Claw servo now uses continuous PWM signalling for improved grip
2025-11-15 Reverted server changes for reliable functionality
    [rpi_control_server.py]
2025-11-15 Removed claw servo interpolation and modified open claw PWM
2025-11-15 Re-added continuous claw servo PWM signalling
2025-11-15 Updated camera config for USB cam
2025-11-15 Fine tuned pitch servo values
2025-11-15 Changed claw closed servo PWM
2025-11-16 Removed unused camera offset variable
2025-12-05 Fix servo config
2025-12-05 Fixed claw servo closed pwm
    [rpi_control_server.py]
